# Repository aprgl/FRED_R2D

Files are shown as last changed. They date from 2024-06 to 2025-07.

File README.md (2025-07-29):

Little Resolver to Digital board for FRED (ABB IRB 2000).

[Ongoing google doc bring-up notes](https://docs.google.com/document/d/1SvePxEv6x2LG5fbGa1SZI07iUhBEWdyZOOTjJPw_SJs)






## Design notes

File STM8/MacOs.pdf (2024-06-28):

MacOs Project
Configuration Report

## 1. Description

1.1. Project
Project Name | MacOs
Board Name | No information
Generated with: | STM8CubeMX 1.5.0
Date | 04/10/2024
1.2. MCU
MCU Series | STM8S
MCU Line | STM8S Value Line
MCU name | STM8S003F3Px
MCU Package | TSSOP20
MCU Pin number | 20

## 2. Pinout Configuration

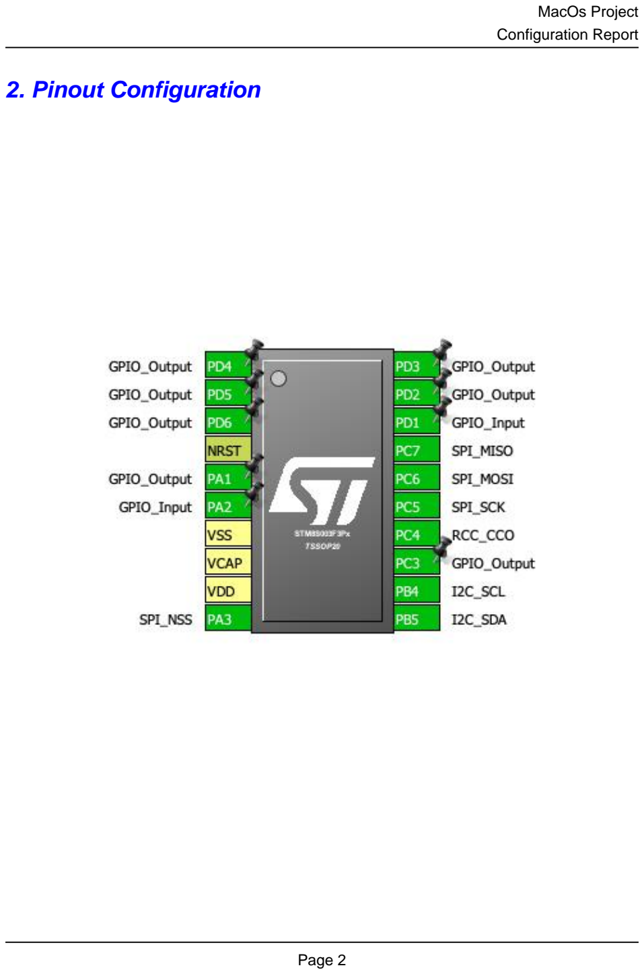
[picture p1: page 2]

## 3. Pins Configuration

Pin Number TSSOP20 | Pin Name (function after reset) | Pin Type | Alternate Function(s) | Label
1 | PD4 * | I/O | GPIO_Output
2 | PD5 * | I/O | GPIO_Output
3 | PD6 * | I/O | GPIO_Output
4 | NRST | Reset
5 | PA1 * | I/O | GPIO_Output
6 | PA2 * | I/O | GPIO_Input
7 | VSS | Power
8 | VCAP | Power
9 | VDD | Power
10 | PA3 | I/O | SPI_NSS
11 | PB5 | I/O | I2C_SDA
12 | PB4 | I/O | I2C_SCL
13 | PC3 * | I/O | GPIO_Output
14 | PC4 | I/O | RCC_CCO
15 | PC5 | I/O | SPI_SCK
16 | PC6 | I/O | SPI_MOSI
17 | PC7 | I/O | SPI_MISO
18 | PD1 * | I/O | GPIO_Input
19 | PD2 * | I/O | GPIO_Output
20 | PD3 * | I/O | GPIO_Output

* The pin is affected with an I/O function

## 4. Clock Tree Configuration

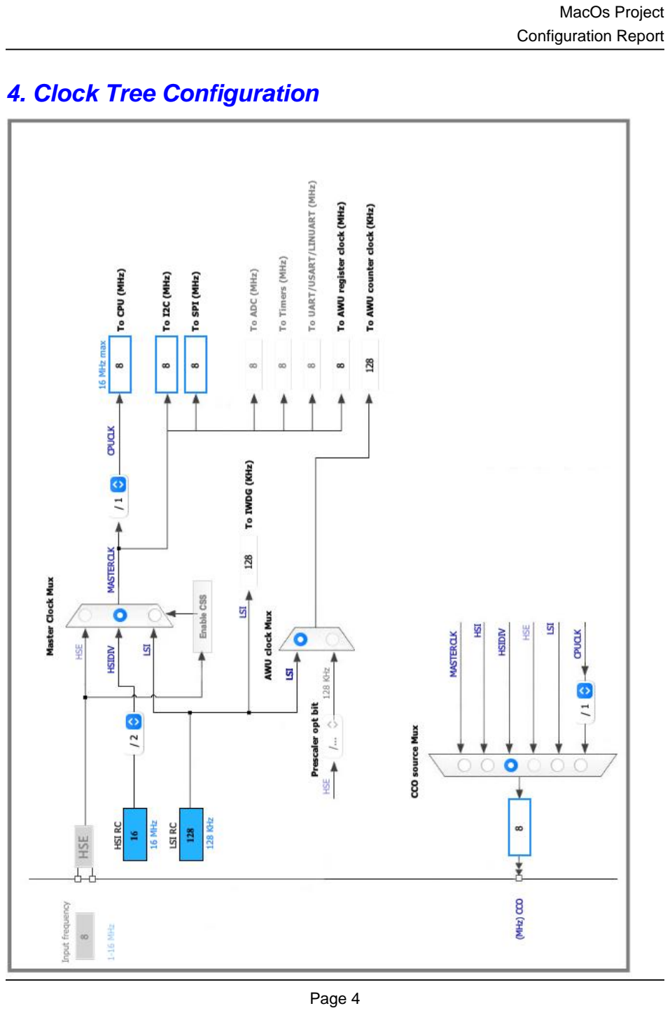
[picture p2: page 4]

## 5. Power Consumption Calculator report

5.1. Microcontroller Selection
Series | STM8S
Line | STM8S Value Line
MCU | STM8S003F3Px
Datasheet | 18576_Rev8
5.2. Parameter Selection
Temperature | 25
Vdd | null

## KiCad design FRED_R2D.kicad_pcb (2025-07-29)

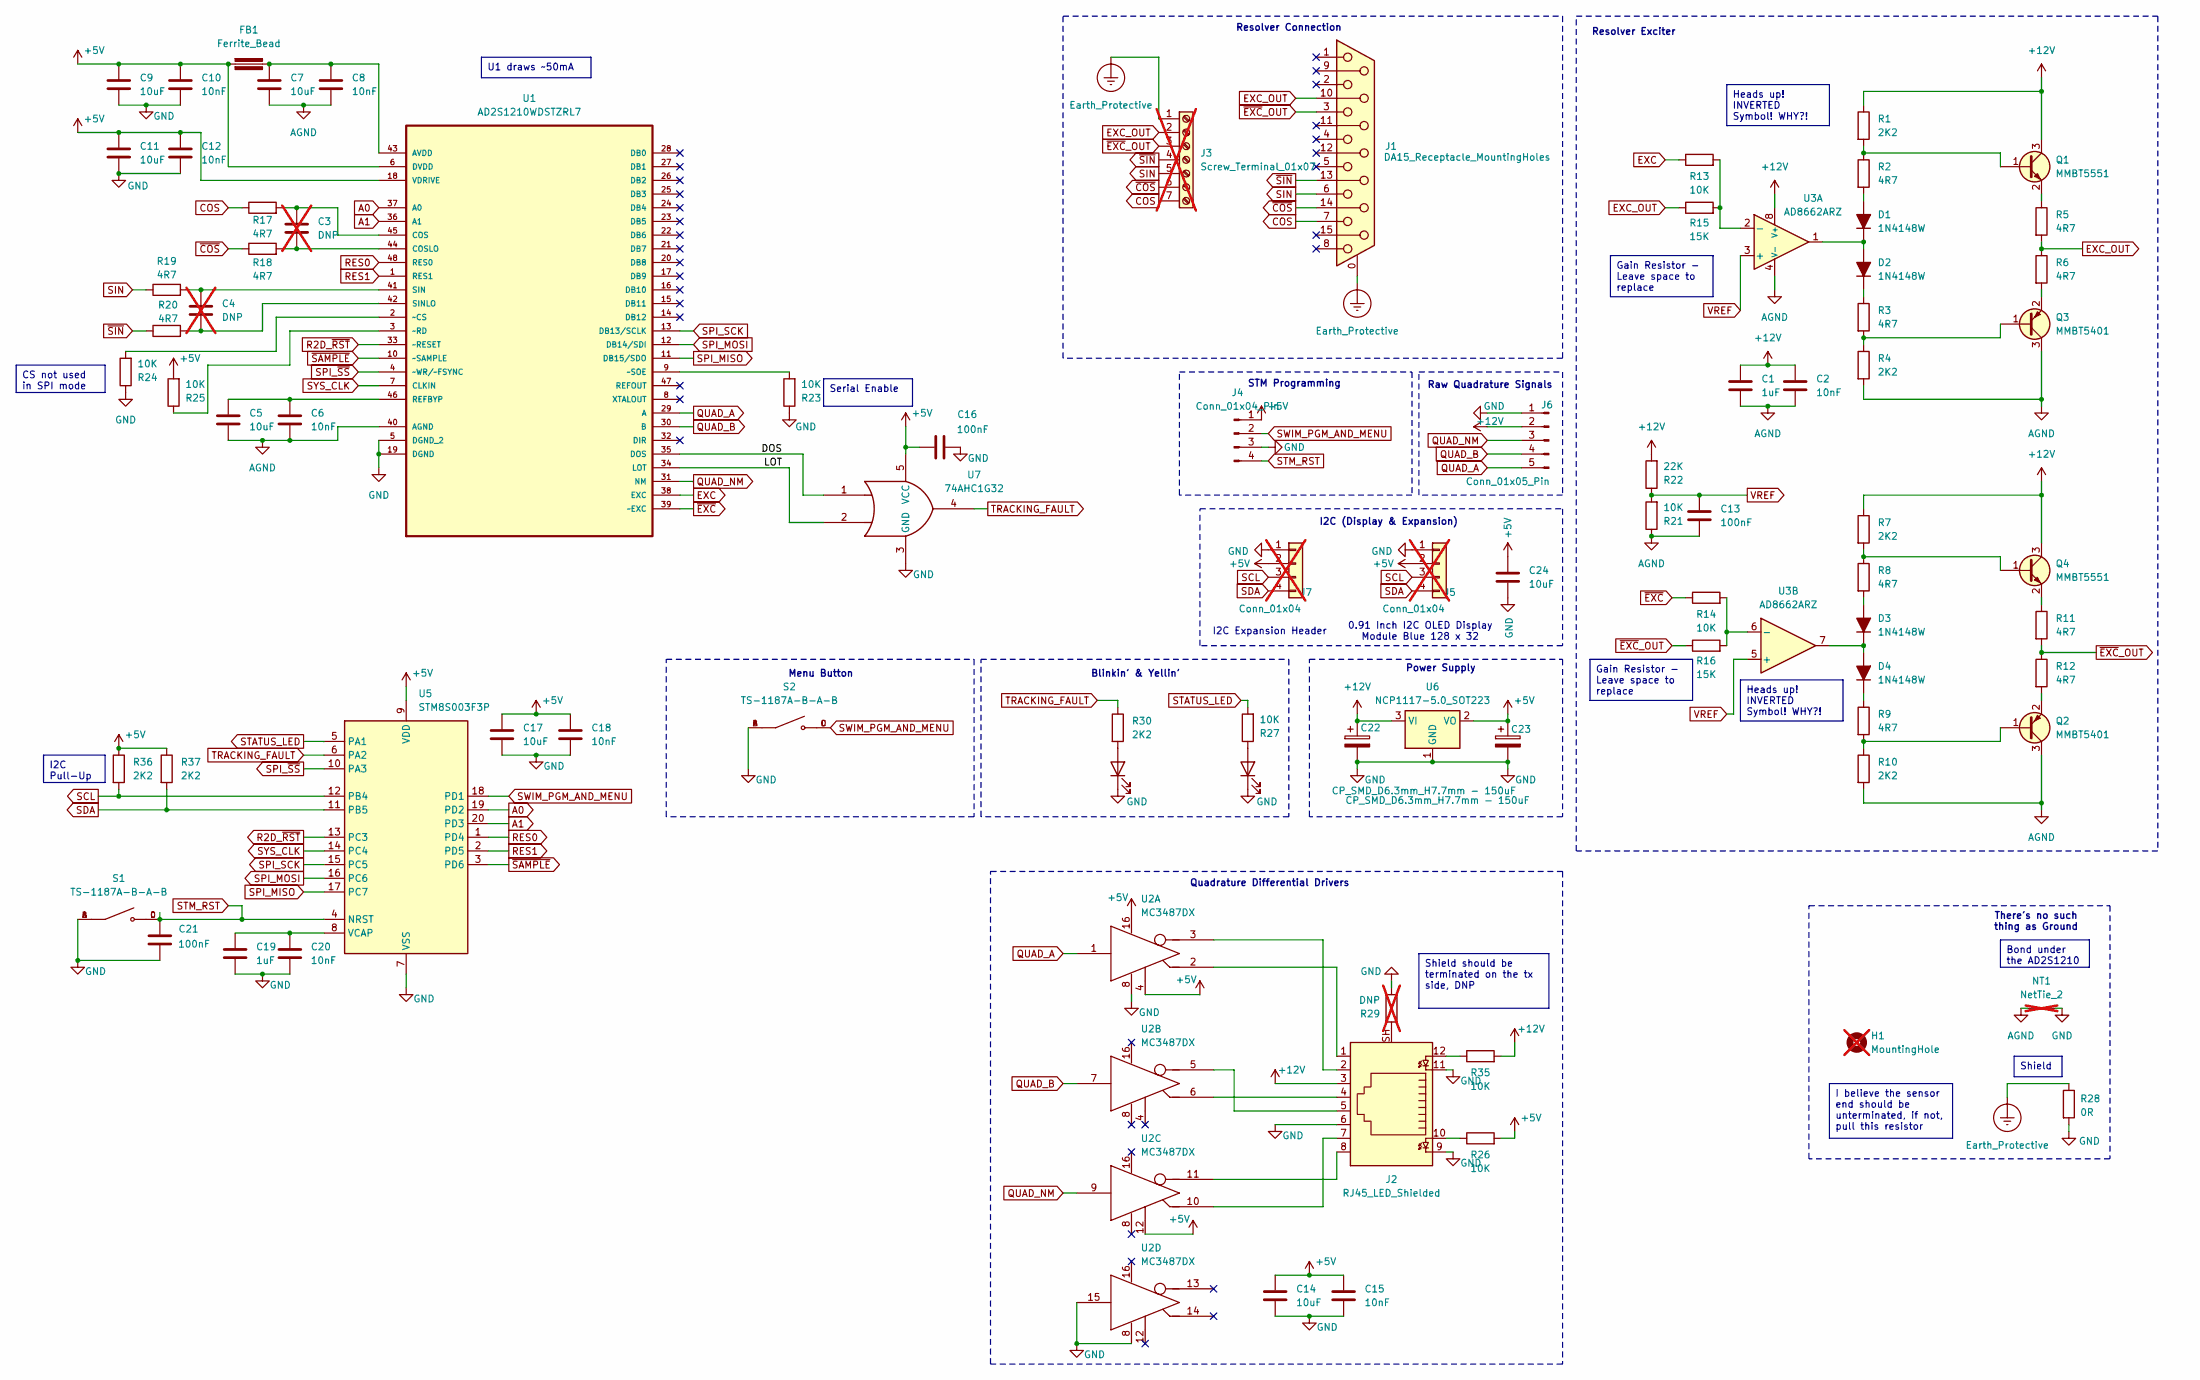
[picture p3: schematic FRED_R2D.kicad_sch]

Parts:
C1, C19: 1uF; C_0603_1608Metric; LCSC C15849
C2, C6, C8, C10, C12, C15, C18, C20: 10nF; C_0603_1608Metric; LCSC C57112
C3, C4: DNP; C_0603_1608Metric; not fitted
C5, C7, C9, C11, C14, C17, C24: 10uF; C_0603_1608Metric; LCSC C96446
C13, C16, C21: 100nF; C_0603_1608Metric; LCSC C14663
C22, C23: CP_SMD_D6.3mm_H7.7mm - 150uF; CP_Elec_6.3x7.7; LCSC C249984
D1, D2, D3, D4: 1N4148W; D_SOD-123; LCSC C81598
D5, D6: LED; LED_0603_1608Metric; LCSC C2286
FB1: Ferrite_Bead; Fuse_0603_1608Metric; LCSC C1002
H1: MountingHole; MountingHole_2.2mm_M2; not fitted
J1: DA15_Receptacle_MountingHoles; DSUB-15_Female_Horizontal_P2.77x2.84mm_EdgePinOffset7.70mm_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; LCSC C77836
J2: RJ45_LED_Shielded; RJ45_Amphenol_RJHSE538X; LCSC C464587
J3: Screw_Terminal_01x07; TerminalBlock_Phoenix_MPT-0,5-7-2.54_1x07_P2.54mm_Horizontal; not fitted
J4: Conn_01x04_Pin; Molex_PicoBlade_53047-0410_1x04_P1.25mm_Vertical
J5, J7: Conn_01x04; PinHeader_1x04_P2.54mm_Vertical; not fitted
J6: Conn_01x05_Pin; JST_PH_B5B-PH-K_1x05_P2.00mm_Vertical; LCSC C157993
NT1: NetTie_2; NetTie-2_SMD_Pad0.5mm; not fitted
Q1, Q4: MMBT5551; SOT-23; LCSC C2145
Q2, Q3: MMBT5401; SOT-23; LCSC C8326
R1, R4, R7, R10, R30, R36, R37: 2K2; R_0603_1608Metric; LCSC C4190
R2, R3, R5, R6, R8, R9, R11, R12, R17, R18, R19, R20: 4R7; R_0603_1608Metric; LCSC C23164
R13, R14, R21, R23, R24, R25, R26, R27, R35: 10K; R_0603_1608Metric; LCSC C25804
R15, R16: 15K; R_0603_1608Metric; LCSC C22809
R22: 22K; R_0603_1608Metric; LCSC C31850
R28: 0R; R_0603_1608Metric; LCSC C21189
R29: DNP; R_0603_1608Metric; not fitted
S1, S2: TS-1187A-B-A-B; SW_TS-1187A-B-A-B; PARTREV A0; LCSC C318884
U1: AD2S1210WDSTZRL7; QFP50P900X900X160-48N; MPN AD2S1210WDSTZRL7; LCSC C459871
U2: MC3487DX; SOIC-16_3.9x9.9mm_P1.27mm; LCSC C7309
U3: AD8662ARZ; SO-8_3.9x4.9mm_P1.27mm; LCSC C28133
U5: STM8S003F3P; TSSOP-20_4.4x6.5mm_P0.65mm; LCSC C52717
U6: NCP1117-5.0_SOT223; SOT-223-3_TabPin2; LCSC C185806
U7: 74AHC1G32; SOT-23-5; LCSC C2861488

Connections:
+5V: C9.1, C10.1, C11.1, C12.1, C14.1, C15.1, C16.1, C17.1, C18.1, C23.1, C24.1, FB1.1, J4.1, J5.2, J7.2, R25.2, R26.2, R36.1, R37.1, U1.6 (DVDD), U1.18 (VDRIVE), U2.4 (ENABLE), U2.12 (ENABLE), U2.16 (VCC), U5.9 (VDD), U6.2 (VO), U7.5 (VCC)
+12V: C1.1, C2.1, C22.1, J2.3, J6.2, Q1.3 (C), Q4.3 (C), R1.1, R7.1, R22.2, R35.2, U3.8 (V+), U6.3 (VI)
/DOS: U1.35 (DOS), U7.1
/LOT: U1.34 (LOT), U7.2
A0: U1.37 (A0), U5.19 (PD2)
A1: U1.36 (A1), U5.20 (PD3)
AGND: C1.2, C2.2, C5.2, C6.2, C7.2, C8.2, C13.2, NT1.1, Q2.3 (C), Q3.3 (C), R4.2, R10.2, R21.1, U1.40 (AGND), U3.4 (V-)
COS: J1.7, J3.7, R17.1
EXC: R13.1, U1.38 (EXC)
EXC_OUT: J1.10, J3.2, R5.2, R6.1, R15.1
Earth_Protective: J1.0 (PAD), J3.1, R28.1
GND: C9.2, C10.2, C11.2, C12.2, C14.2, C15.2, C16.2, C17.2, C18.2, C19.2, C20.2, C21.1, C22.2, C23.2, C24.2, D5.1 (K), D6.1 (K), J2.6, J2.9, J2.11, J4.3, J5.1, J6.1, J7.1, NT1.2, R23.1, R24.1, R28.2, R29.2, S1.A, S1.B, S2.A, S2.B, U1.5 (DGND_2), U1.19 (DGND), U2.8 (GND), U2.15 (INPUT), U5.7 (VSS), U6.1 (GND), U7.3 (GND)
unnamed: D1.2 (A), R2.2
unnamed: D1.1 (K), D2.2 (A), U3.1
unnamed: D2.1 (K), R3.1
unnamed: D3.2 (A), R8.2
unnamed: D3.1 (K), D4.2 (A), U3.7
unnamed: D4.1 (K), R9.1
unnamed: D5.2 (A), R27.1
unnamed: D6.2 (A), R30.2
unnamed: J2.10, R26.1
unnamed: J2.12, R35.1
unnamed: J2.SH, R29.1
unnamed: Q1.1 (B), R1.2, R2.1
unnamed: Q1.2 (E), R5.1
unnamed: Q2.1 (B), R9.2, R10.1
unnamed: Q2.2 (E), R12.2
unnamed: Q3.1 (B), R3.2, R4.1
unnamed: Q3.2 (E), R6.2
unnamed: Q4.1 (B), R7.2, R8.1
unnamed: Q4.2 (E), R11.1
unnamed: C7.1, C8.1, FB1.2, U1.43 (AVDD)
unnamed: C3.1, R17.2, U1.45 (COS)
unnamed: C3.2, R18.2, U1.44 (COSLO)
unnamed: C5.1, C6.1, U1.46 (REFBYP)
unnamed: C4.1, R19.2, U1.41 (SIN)
unnamed: C4.2, R20.2, U1.42 (SINLO)
unnamed: R24.2, U1.2 (~CS)
unnamed: R25.1, U1.3 (~RD)
unnamed: R23.2, U1.9 (~SOE)
unnamed: J2.1, U2.2 (OUT+)
unnamed: J2.2, U2.3 (OUT-)
unnamed: J2.4, U2.6 (OUT+)
unnamed: J2.5, U2.5 (OUT-)
unnamed: J2.7, U2.10 (OUT+)
unnamed: J2.8, U2.11 (OUT-)
unnamed: R13.2, R15.2, U3.2 (-)
unnamed: R14.2, R16.2, U3.6 (-)
unnamed: C19.1, C20.1, U5.8 (VCAP)
QUAD_A: J6.5, U1.29 (A), U2.1 (INPUT)
QUAD_B: J6.4, U1.30 (B), U2.7 (INPUT)
QUAD_NM: J6.3, U1.31 (NM), U2.9 (INPUT)
R2D_~RST: U1.33 (~RESET), U5.13 (PC3)
RES0: U1.48 (RES0), U5.1 (PD4)
RES1: U1.1 (RES1), U5.2 (PD5)
SCL: J5.3, J7.3, R36.2, U5.12 (PB4)
SDA: J5.4, J7.4, R37.2, U5.11 (PB5)
SIN: J1.6, J3.5, R19.1
SPI_MISO: U1.11 (DB15/SDO), U5.17 (PC7)
SPI_MOSI: U1.12 (DB14/SDI), U5.16 (PC6)
SPI_SCK: U1.13 (DB13/SCLK), U5.15 (PC5)
SPI_~SS: U1.4 (~WR/~FSYNC), U5.10 (PA3)
STATUS_LED: R27.2, U5.5 (PA1)
STM_RST: C21.2, J4.4, S1.C, S1.D, U5.4 (NRST)
SWIM_PGM_AND_MENU: J4.2, S2.C, S2.D, U5.18 (PD1)
SYS_CLK: U1.7 (CLKIN), U5.14 (PC4)
TRACKING_FAULT: R30.1, U5.6 (PA2), U7.4
VREF: C13.1, R21.2, R22.1, U3.3 (+), U3.5 (+)
~COS: J1.14, J3.6, R18.1
~EXC: R14.1, U1.39 (~EXC)
~EXC_OUT: J1.3, J3.3, R11.2, R12.1, R16.1
~SAMPLE: U1.10 (~SAMPLE), U5.3 (PD6)
~SIN: J1.13, J3.4, R20.1

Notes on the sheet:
I2C Pull-Up
Bond under the AD2S1210
Gain Resistor - Leave space to replace
Heads up! INVERTED Symbol! WHY?!
CS not used in SPI mode
Shield should be terminated on the tx side, DNP
I believe the sensor end should be unterminated, if not, pull this resistor
Shield
U1 draws ~50mA
Serial Enable
I2C Expansion Header
Power Supply
Quadrature Differential Drivers
Blinkin' & Yellin'
STM Programming
Raw Quadrature Signals
Resolver Connection
Resolver Exciter
I2C (Display & Expansion)
There's no such thing as Ground
Menu Button
0.91 Inch I2C OLED Display Module Blue 128 x 32

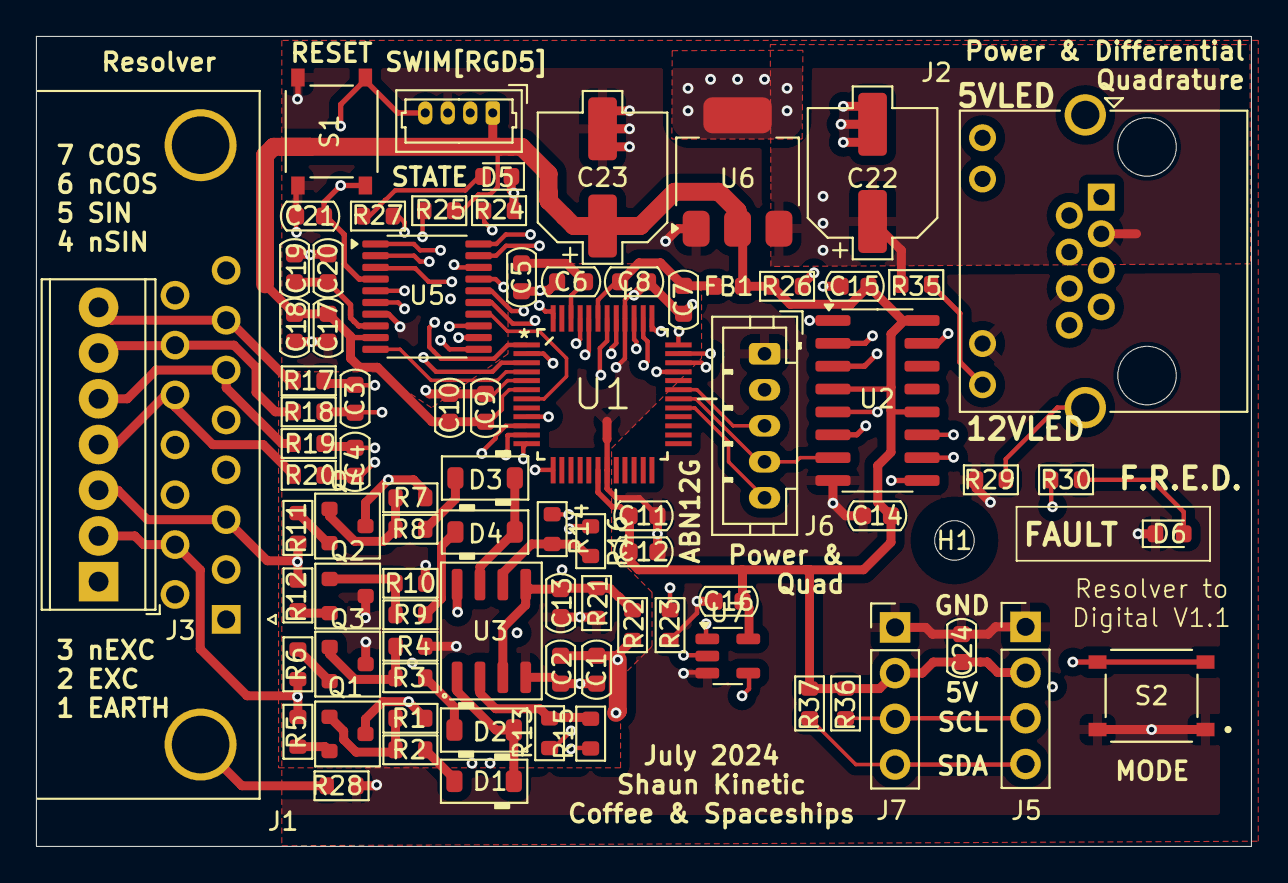
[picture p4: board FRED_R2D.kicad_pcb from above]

Board: 4 copper layers, 67.5 x 45.0 mm, 85 parts (0 on the bottom side), 73 nets.

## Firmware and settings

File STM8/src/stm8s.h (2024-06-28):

/**
  ******************************************************************************
  * @file    stm8s.h
  * @author  MCD Application Team
  * @version V2.3.0
  * @date    16-June-2017
  * @brief   This file contains all HW registers definitions and memory mapping.
   ******************************************************************************
  * @attention
  *
  * <h2><center>&copy; COPYRIGHT 2014 STMicroelectronics</center></h2>
  *
  * Licensed under MCD-ST Liberty SW License Agreement V2, (the "License");
  * You may not use this file except in compliance with the License.
  * You may obtain a copy of the License at:
  *
  *        http://www.st.com/software_license_agreement_liberty_v2
  *
  * Unless required by applicable law or agreed to in writing, software 
  * distributed under the License is distributed on an "AS IS" BASIS, 
  * WITHOUT WARRANTIES OR CONDITIONS OF ANY KIND, either express or implied.
  * See the License for the specific language governing permissions and
  * limitations under the License.
  *
  ******************************************************************************
  */

/* Define to prevent recursive inclusion -------------------------------------*/
#ifndef __STM8S_H
#define __STM8S_H

/** @addtogroup STM8S_StdPeriph_Driver
  * @{
  */
  
/* Uncomment the line below according to the target STM8S or STM8A device used in your
   application. */

 /* #define STM8S208 */      /*!< STM8S High density devices with CAN */
 /* #define STM8S207 */      /*!< STM8S High density devices without CAN */
 /* #define STM8S007 */      /*!< STM8S Value Line High density devices */
 /* #define STM8AF52Ax */    /*!< STM8A High density devices with CAN */
 /* #define STM8AF62Ax */    /*!< STM8A High density devices without CAN */
 /* #define STM8S105 */      /*!< STM8S Medium density devices */
 /* #define STM8S005 */      /*!< STM8S Value Line Medium density devices */
 /* #define STM8AF626x */    /*!< STM8A Medium density devices */
 /* #define STM8AF622x */    /*!< STM8A Low density devices */
 /* #define STM8S103 */      /*!< STM8S Low density devices */
  #define STM8S003       /*!< STM8S Value Line Low density devices */
 /* #define STM8S903 */      /*!< STM8S Low density devices */
 /* #define STM8S001 */      /*!< STM8S Value Line Low denisty devices */

/*   Tip: To avoid modifying this file each time you need to switch between these
        devices, you can define the device in your toolchain compiler preprocessor. 

  - High-Density STM8A devices are the STM8AF52xx STM8AF6269/8x/Ax,
    STM8AF51xx, and STM8AF6169/7x/8x/9x/Ax microcontrollers where the Flash memory
    density ranges between 32 to 128 Kbytes
  - Medium-Density STM8A devices are the STM8AF622x/4x, STM8AF6266/68,
    STM8AF612x/4x, and STM8AF6166/68 microcontrollers where the Flash memory 
    density ranges between 8 to 32 Kbytes
  - High-Density STM8S devices are the STM8S207xx, STM8S007 and STM8S208xx microcontrollers
    where the Flash memory density ranges between 32 to 128 Kbytes.
  - Medium-Density STM8S devices are the STM8S105x and STM8S005 microcontrollers
    where the Flash memory density ranges between 16 to 32-Kbytes.
  - Low-Density STM8A devices are the STM8AF622x microcontrollers where the Flash
    density is 8 Kbytes. 
  - Low-Density STM8S devices are the STM8S103xx, STM8S003, STM8S903xx and STM8S001 microcontrollers
    where the Flash density is 8 Kbytes. */

#if !defined (STM8S208) && !defined (STM8S207) && !defined (STM8S105) && \
    !defined (STM8S103) && !defined (STM8S903) && !defined (STM8AF52Ax) && \
    !defined (STM8AF62Ax) && !defined (STM8AF626x) && !defined (STM8S007) && \
    !defined (STM8S003)&& !defined (STM8S005) && !defined(STM8S001) && !defined (STM8AF622x) 
 #error "Please select first the target STM8S/A device used in your application (in stm8s.h file)"
#endif

/**
  * @brief  Definition of Device on-chip RC oscillator frequencies
  */
#define HSI_VALUE   ((uint32_t)16000000) /*!< Typical Value of the HSI in Hz */
#define LSI_VALUE   ((uint32_t)128000)   /*!< Typical Value of the LSI in Hz */

#define FAR  __far
#define NEAR __near
#define TINY __tiny
#define EEPROM __eeprom
#define CONST  const


/* For FLASH routines, select whether pointer will be declared as near (2 bytes,
   to handle code smaller than 64KB) or far (3 bytes, to handle code larger 
   than 64K) */

#if defined (STM8S105) || defined (STM8S005) || defined (STM8S103) || defined (STM8S003) || \
    defined (STM8S001) || defined (STM8S903) || defined (STM8AF626x) || defined (STM8AF622x)
/*!< Used with memory Models for code smaller than 64K */
 #define PointerAttr NEAR
 #define MemoryAddressCast uint16_t
#else /* STM8S208 or STM8S207 or STM8AF62Ax or STM8AF52Ax */
/*!< Used with memory Models for code higher than 64K */
 #define PointerAttr FAR
 #define MemoryAddressCast uint32_t
#endif /* STM8S105 or STM8S103 or STM8S003 or STM8S001 or STM8S903 or STM8AF626x or STM8AF622x */

/* Uncomment the line below to enable the FLASH functions execution from RAM */
#if !defined (RAM_EXECUTION)
/* #define RAM_EXECUTION  (1) */
#endif /* RAM_EXECUTION */

#ifdef RAM_EXECUTION
 #ifdef _COSMIC_
   #define IN_RAM(a) a
 #elif defined (_RAISONANCE_) /* __RCST7__ */
   #define IN_RAM(a) a inram
 #else /*_IAR_*/
  #define IN_RAM(a) __ramfunc a
 #endif /* _COSMIC_ */
#else 
  #define IN_RAM(a) a
#endif /* RAM_EXECUTION */

/*!< [31:16] STM8S Standard Peripheral Library main version V2.3.0*/
#define __STM8S_STDPERIPH_VERSION_MAIN   ((uint8_t)0x02) /*!< [31:24] main version */                                  
#define __STM8S_STDPERIPH_VERSION_SUB1   ((uint8_t)0x03) /*!< [23:16] sub1 version */
#define __STM8S_STDPERIPH_VERSION_SUB2   ((uint8_t)0x00) /*!< [15:8]  sub2 version */
#define __STM8S_STDPERIPH_VERSION_RC     ((uint8_t)0x00) /*!< [7:0]  release candidate */ 
#define __STM8S_STDPERIPH_VERSION       ( (__STM8S_STDPERIPH_VERSION_MAIN << 24)\
                                          |(__STM8S_STDPERIPH_VERSION_SUB1 << 16)\
                                          |(__STM8S_STDPERIPH_VERSION_SUB2 << 8)\
                                          |(__STM8S_STDPERIPH_VERSION_RC))

/******************************************************************************/

/* Includes ------------------------------------------------------------------*/

/* Exported types and constants ----------------------------------------------*/

/** @addtogroup Exported_types
  * @{
  */

/**
 * IO definitions
 *
 * define access restrictions to peripheral registers
 */
#define     __I     volatile const   /*!< defines 'read only' permissions     */
#define     __O     volatile         /*!< defines 'write only' permissions    */
#define     __IO    volatile         /*!< defines 'read / write' permissions  */

/*!< Signed integer types  */
typedef   signed char     int8_t;
typedef   signed short    int16_t;
typedef   signed long     int32_t;
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

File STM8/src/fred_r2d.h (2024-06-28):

/*
 * Port & Pin Definitions for FRED R2D Board V1.0
 * As well as I2C and other board-specific defines
 */

#ifndef _FRED_R2D_H
#define _FRED_R2D_H

#define DISPLAY_WRITE_ADDRESS1        0x50

// ******** LED ******** //
#define LED_PORT    PA
#define LED_PIN     PIN1

/* ******** I2C Display  ******** 
IC: SSD1306
Size: 0.9 inch
Resolution: 128 X 32 pixels
******************************* */

#define SSD1306_I2C 		I2C
#define SSD1306_I2C_CLK 	CLK_PERIPHERAL_I2C

#define SSD1306_SCL_PORT    PB
#define SSD1306_SCL_PIN     PIN4
#define SSD1306_SDA_PORT    PB
#define SSD1306_SDA_PIN     PIN5

// ******** R2D ******** //
#define R2D_TRACKING_FAULT_PORT PA
#define R2D_TRACKING_FAULT_PIN  PIN2

#define R2D_RST_PORT    PC

#define R2D_SPI_SS_PORT PA
#define R2D_SYS_CLK_PORT    PC
#define R2D_SPI_SCK_PORT    PC
#define R2D_SPI_MOSI_PORT   PC
#define R2D_SPI_MISO_PORT   PC

#define R2D_RST_PIN     PIN3

#define R2D_SPI_SS_PIN  PIN3
#define R2D_SYS_CLK_PIN     PIN4
#define R2D_SPI_SCK_PIN     PIN5
#define R2D_SPI_MOSI_PIN    PIN6
#define R2D_SPI_MISO_PIN    PIN7

#define R2D_A0_PORT     PD
#define R2D_A1_PORT     PD
#define R2D_RES0_PORT   PD
#define R2D_RES1_PORT   PD
#define R2D_SAMPLE_PORT PD

#define R2D_A0_PIN      PIN2
#define R2D_A1_PIN      PIN3
#define R2D_RES0_PIN    PIN4
#define R2D_RES1_PIN    PIN5
#define R2D_SAMPLE_PIN  PIN6

// Functions

void board_setup(void);

#endif

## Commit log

2024-06-25 Added git ignore for kicad
2024-06-28 V1.0 Commit
    [FRED_R2D.kicad_pcb, FRED_R2D.kicad_sch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]
2024-06-28 Fxied name issue, reverted to compiling blinky
    [blink.c, fred_r2d.h]
2025-07-29 Version 1.1 for mfg
    [FRED_R2D.kicad_pcb, FRED_R2D.kicad_sch]

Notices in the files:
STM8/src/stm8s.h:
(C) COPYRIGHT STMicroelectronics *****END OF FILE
